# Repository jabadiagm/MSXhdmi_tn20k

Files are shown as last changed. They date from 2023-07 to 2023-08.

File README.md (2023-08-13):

# MSXhdmi_tn20k
Adaptador hdmi para MSX1 / MSX1 hdmi adapter

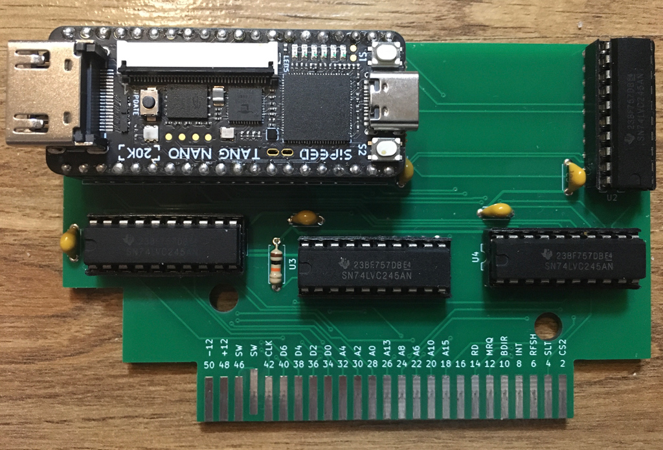
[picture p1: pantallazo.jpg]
Pantallazo


Permite conectar un MSX de primera generación a un monitor convencional. La lógica está contenida en una Tang Nano 20K que se encarga de reproducir imagen (vdp) y sonido (psg + fm + scc). Parcialmente compatible con el software MSX2. Adaptación del vdp V9958 escrita por [lfantoniosi](https://github.com/lfantoniosi).

Configuración de sofarun para utilizar scc externa:

[https://www.msx.org/forum/msx-talk/hardware/report-konami-scc-standalone-with-sofarun](https://www.msx.org/forum/msx-talk/hardware/report-konami-scc-standalone-with-sofarun)

Allows the conection between a first generation MSX and a conventional monitor. Logic is contained in a Tang Nano 20K which is in charge of playing picture (vdp) and sound (psg + fm + scc). Partially compatible with MSX2 software. V9958 adapted by [lfantoniosi](https://github.com/lfantoniosi).

sofarun config using external scc:

[https://www.msx.org/forum/msx-talk/hardware/report-konami-scc-standalone-with-sofarun](https://www.msx.org/forum/msx-talk/hardware/report-konami-scc-standalone-with-sofarun)

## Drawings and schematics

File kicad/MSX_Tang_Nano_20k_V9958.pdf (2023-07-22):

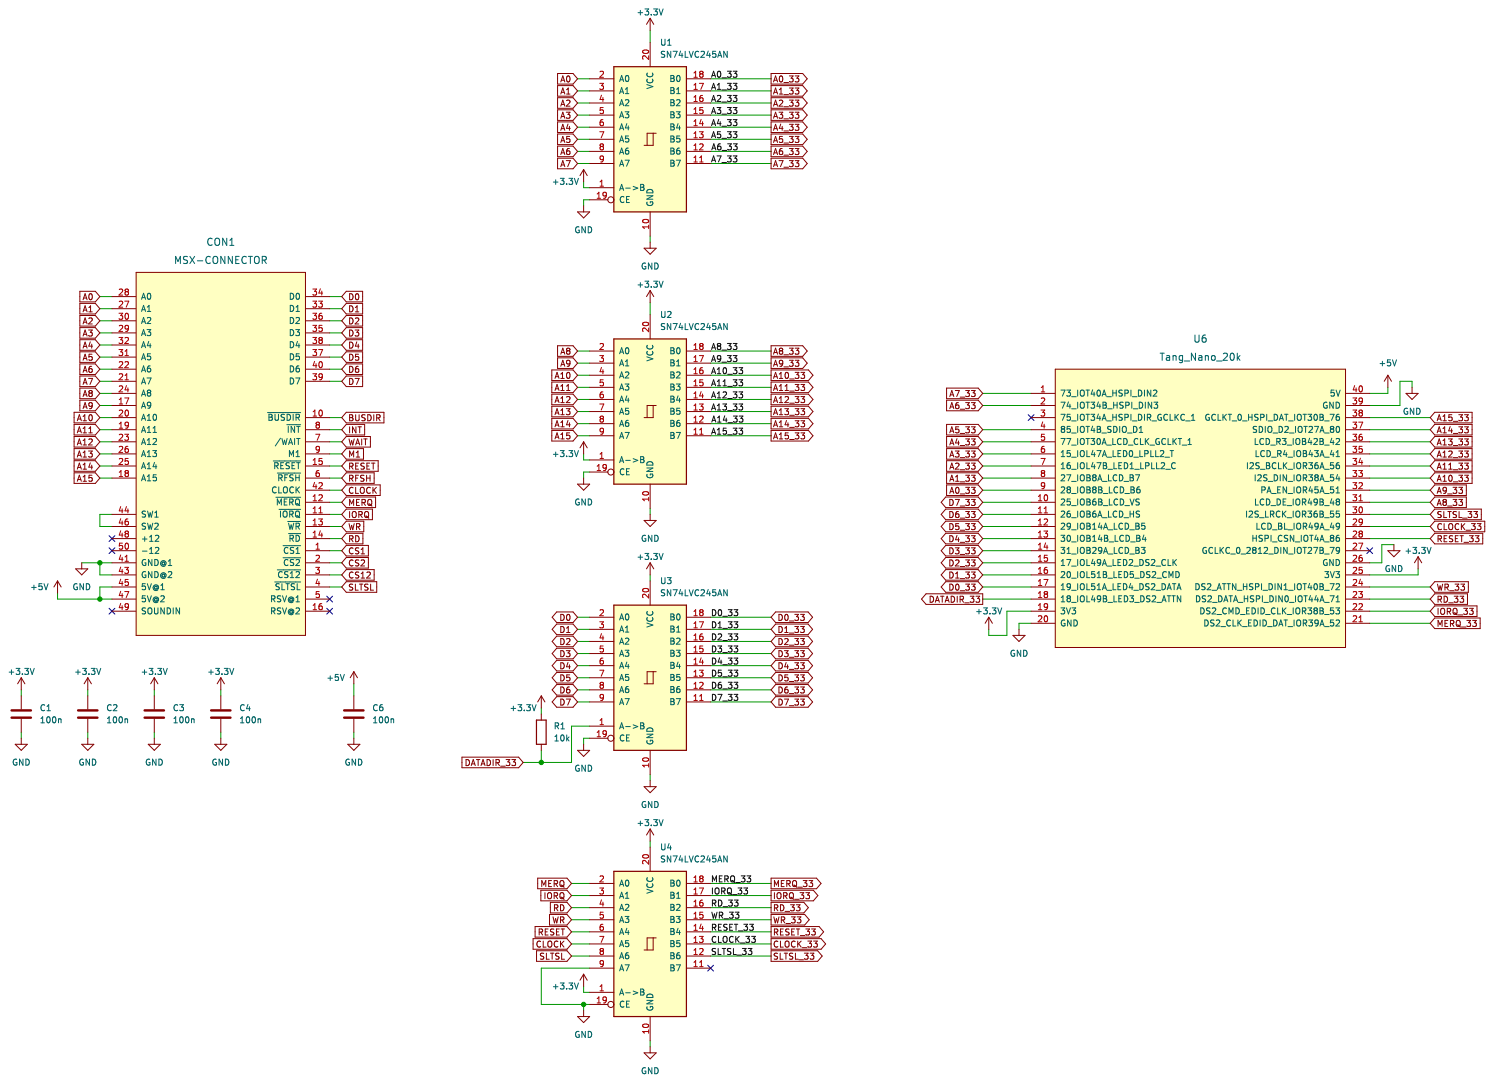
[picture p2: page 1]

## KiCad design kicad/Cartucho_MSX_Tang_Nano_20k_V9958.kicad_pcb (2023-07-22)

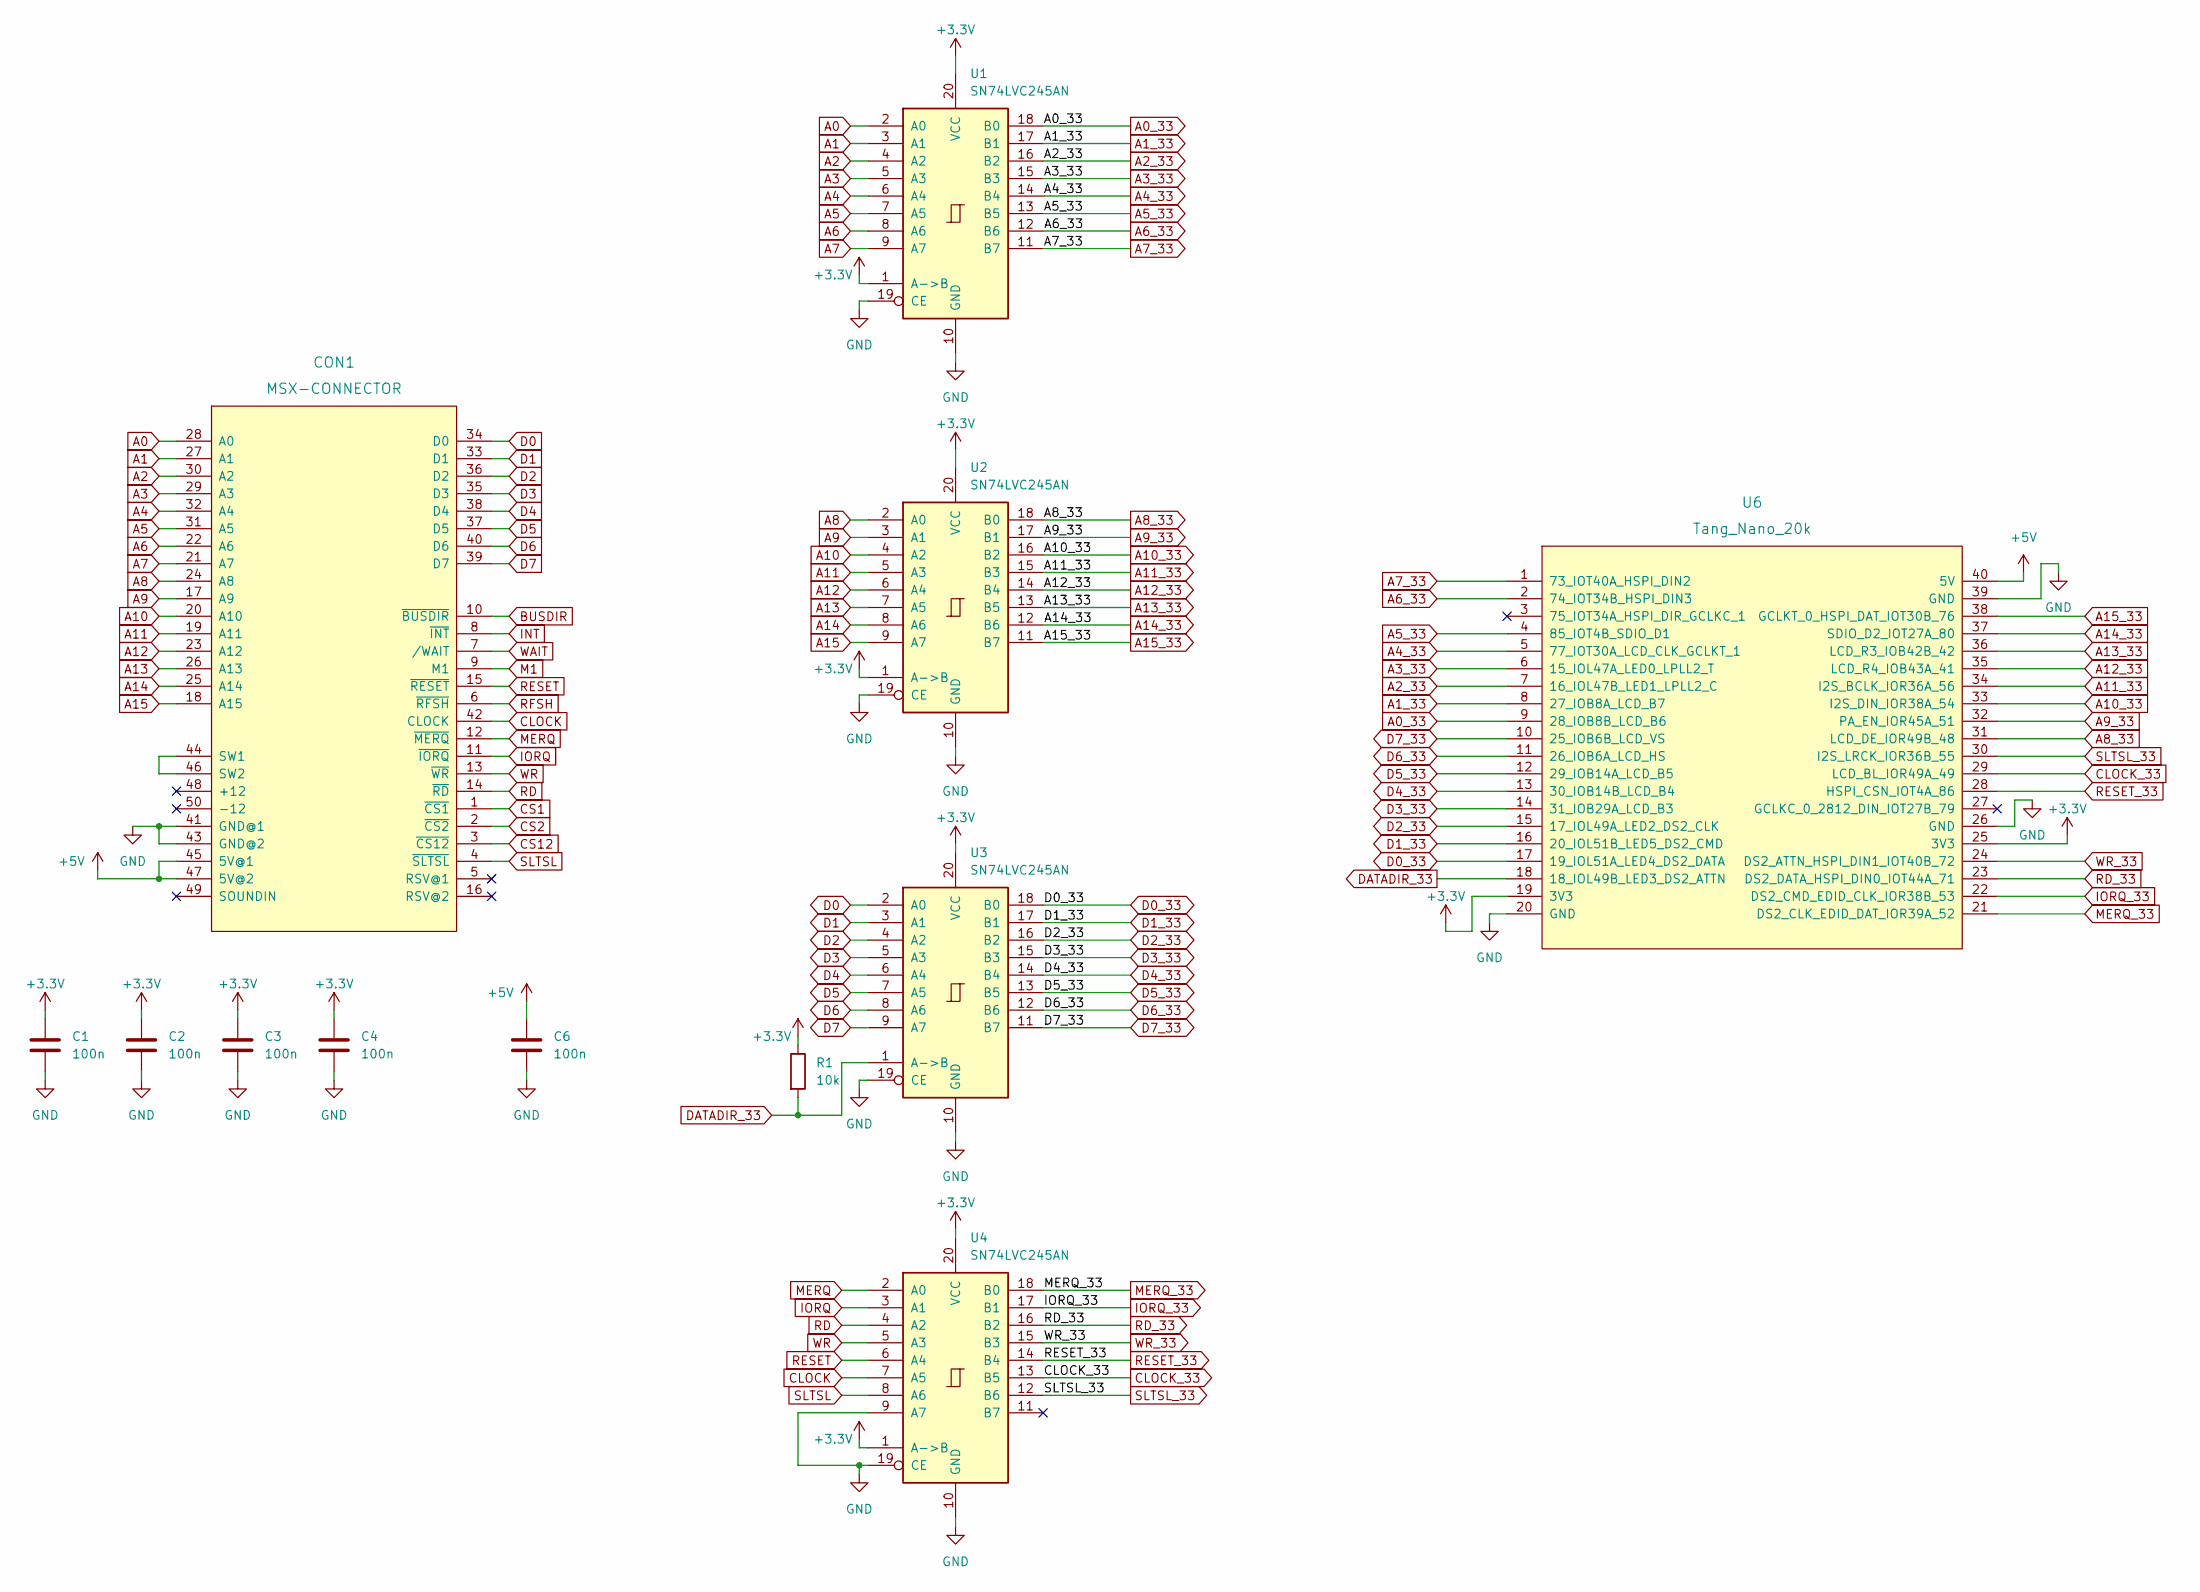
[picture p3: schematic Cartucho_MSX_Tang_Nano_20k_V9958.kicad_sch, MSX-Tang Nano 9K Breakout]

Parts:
C1, C2, C3, C4, C6: 100n; C_Disc_D4.3mm_W1.9mm_P5.00mm
CON1: MSX-CONNECTOR; CARTRIDGE_MSX
R1: 10k; R_Axial_DIN0207_L6.3mm_D2.5mm_P7.62mm_Horizontal
U1, U2, U3, U4: SN74LVC245AN; DIP-20_W7.62mm_LongPads
U6: Tang_Nano_20k

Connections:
+3.3V: C1.1, C2.1, C3.1, C4.1, R1.1, U1.1 (A->B), U1.20 (VCC), U2.1 (A->B), U2.20 (VCC), U3.20 (VCC), U4.1 (A->B), U4.20 (VCC), U6.19 (3V3), U6.25 (3V3)
+5V: C6.1, CON1.45 (5V@1), CON1.47 (5V@2), U6.40 (5V)
A0: CON1.28 (A0), U1.2 (A0)
A0_33: U1.18 (B0), U6.9 (28_IOB8B_LCD_B6)
A1: CON1.27 (A1), U1.3 (A1)
A1_33: U1.17 (B1), U6.8 (27_IOB8A_LCD_B7)
A2: CON1.30 (A2), U1.4 (A2)
A2_33: U1.16 (B2), U6.7 (16_IOL47B_LED1_LPLL2_C)
A3: CON1.29 (A3), U1.5 (A3)
A3_33: U1.15 (B3), U6.6 (15_IOL47A_LED0_LPLL2_T)
A4: CON1.32 (A4), U1.6 (A4)
A4_33: U1.14 (B4), U6.5 (77_IOT30A_LCD_CLK_GCLKT_1)
A5: CON1.31 (A5), U1.7 (A5)
A5_33: U1.13 (B5), U6.4 (85_IOT4B_SDIO_D1)
A6: CON1.22 (A6), U1.8 (A6)
A6_33: U1.12 (B6), U6.2 (74_IOT34B_HSPI_DIN3)
A7: CON1.21 (A7), U1.9 (A7)
A7_33: U1.11 (B7), U6.1 (73_IOT40A_HSPI_DIN2)
A8: CON1.24 (A8), U2.2 (A0)
A8_33: U2.18 (B0), U6.31 (LCD_DE_IOR49B_48)
A9: CON1.17 (A9), U2.3 (A1)
A9_33: U2.17 (B1), U6.32 (PA_EN_IOR45A_51)
A10: CON1.20 (A10), U2.4 (A2)
A10_33: U2.16 (B2), U6.33 (I2S_DIN_IOR38A_54)
A11: CON1.19 (A11), U2.5 (A3)
A11_33: U2.15 (B3), U6.34 (I2S_BCLK_IOR36A_56)
A12: CON1.23 (A12), U2.6 (A4)
A12_33: U2.14 (B4), U6.35 (LCD_R4_IOB43A_41)
A13: CON1.26 (A13), U2.7 (A5)
A13_33: U2.13 (B5), U6.36 (LCD_R3_IOB42B_42)
A14: CON1.25 (A14), U2.8 (A6)
A14_33: U2.12 (B6), U6.37 (SDIO_D2_IOT27A_80)
A15: CON1.18 (A15), U2.9 (A7)
A15_33: U2.11 (B7), U6.38 (GCLKT_0_HSPI_DAT_IOT30B_76)
BUSDIR: CON1.10 (~BUSDIR)
CLOCK: CON1.42 (CLOCK), U4.7 (A5)
CLOCK_33: U4.13 (B5), U6.29 (LCD_BL_IOR49A_49)
CS1: CON1.1 (~CS1)
CS2: CON1.2 (~CS2)
CS12: CON1.3 (~CS12)
D0: CON1.34 (D0), U3.2 (A0)
D0_33: U3.18 (B0), U6.17 (19_IOL51A_LED4_DS2_DATA)
D1: CON1.33 (D1), U3.3 (A1)
D1_33: U3.17 (B1), U6.16 (20_IOL51B_LED5_DS2_CMD)
D2: CON1.36 (D2), U3.4 (A2)
D2_33: U3.16 (B2), U6.15 (17_IOL49A_LED2_DS2_CLK)
D3: CON1.35 (D3), U3.5 (A3)
D3_33: U3.15 (B3), U6.14 (31_IOB29A_LCD_B3)
D4: CON1.38 (D4), U3.6 (A4)
D4_33: U3.14 (B4), U6.13 (30_IOB14B_LCD_B4)
D5: CON1.37 (D5), U3.7 (A5)
D5_33: U3.13 (B5), U6.12 (29_IOB14A_LCD_B5)
D6: CON1.40 (D6), U3.8 (A6)
D6_33: U3.12 (B6), U6.11 (26_IOB6A_LCD_HS)
D7: CON1.39 (D7), U3.9 (A7)
D7_33: U3.11 (B7), U6.10 (25_IOB6B_LCD_VS)
DATADIR_33: R1.2, U3.1 (A->B), U6.18 (18_IOL49B_LED3_DS2_ATTN)
GND: C1.2, C2.2, C3.2, C4.2, C6.2, CON1.41 (GND@1), CON1.43 (GND@2), U1.10 (GND), U1.19 (CE), U2.10 (GND), U2.19 (CE), U3.10 (GND), U3.19 (CE), U4.9 (A7), U4.10 (GND), U4.19 (CE), U6.20 (GND), U6.26 (GND), U6.39 (GND)
INT: CON1.8 (~INT)
IORQ: CON1.11 (~IORQ), U4.3 (A1)
IORQ_33: U4.17 (B1), U6.22 (DS2_CMD_EDID_CLK_IOR38B_53)
M1: CON1.9 (M1)
MERQ: CON1.12 (~MERQ), U4.2 (A0)
MERQ_33: U4.18 (B0), U6.21 (DS2_CLK_EDID_DAT_IOR39A_52)
unnamed: CON1.44 (SW1), CON1.46 (SW2)
RD: CON1.14 (~RD), U4.4 (A2)
RD_33: U4.16 (B2), U6.23 (DS2_DATA_HSPI_DIN0_IOT44A_71)
RESET: CON1.15 (~RESET), U4.6 (A4)
RESET_33: U4.14 (B4), U6.28 (HSPI_CSN_IOT4A_86)
RFSH: CON1.6 (~RFSH)
SLTSL: CON1.4 (~SLTSL), U4.8 (A6)
SLTSL_33: U4.12 (B6), U6.30 (I2S_LRCK_IOR36B_55)
WAIT: CON1.7 (/WAIT)
WR: CON1.13 (~WR), U4.5 (A3)
WR_33: U4.15 (B3), U6.24 (DS2_ATTN_HSPI_DIN1_IOT40B_72)

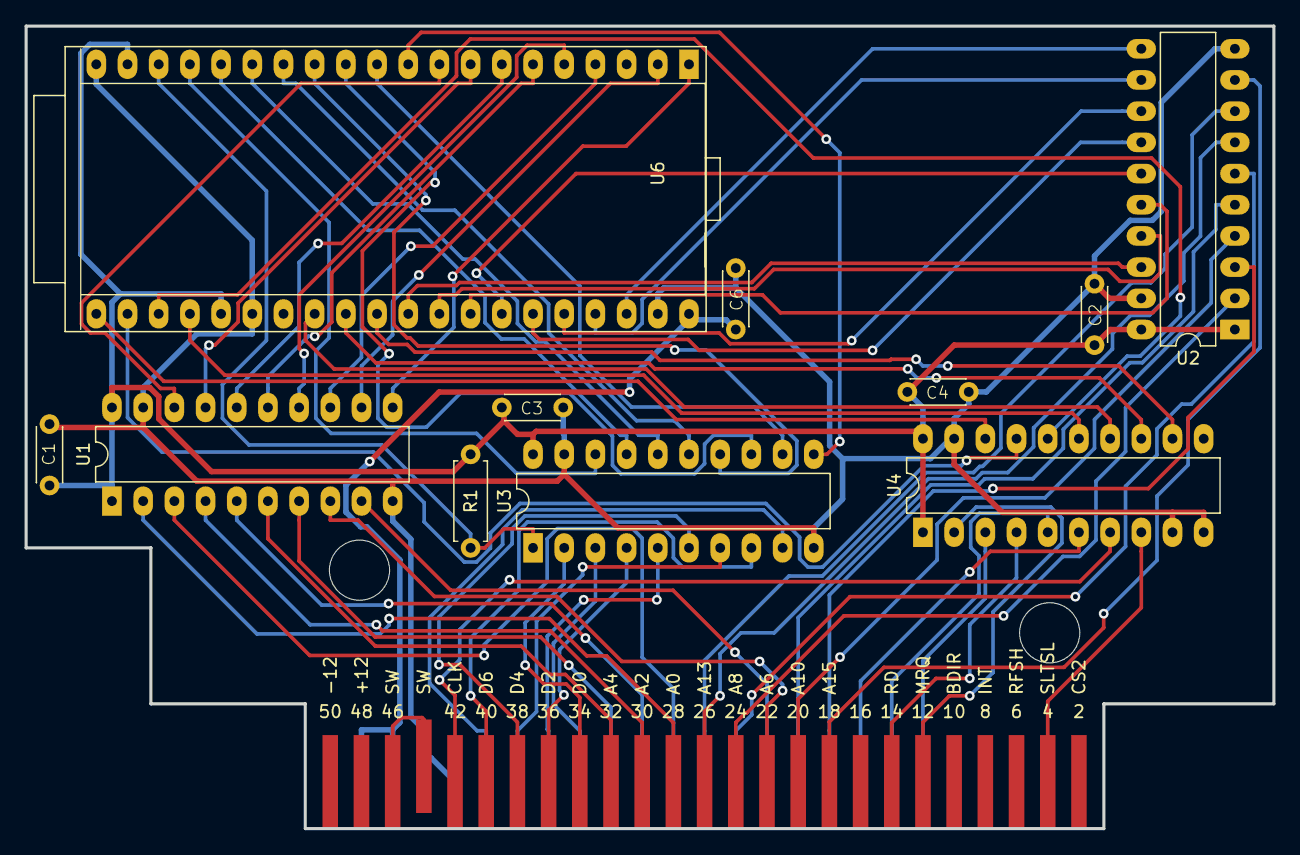
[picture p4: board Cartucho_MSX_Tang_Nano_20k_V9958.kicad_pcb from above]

Board: 2 copper layers, 101.6 x 65.3 mm, 12 parts (0 on the bottom side), 67 nets.

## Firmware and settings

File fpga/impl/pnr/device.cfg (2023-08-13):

set JTAG regular_io = false
set SSPI regular_io = true
set MSPI regular_io = false
set READY regular_io = false
set DONE regular_io = false
set RECONFIG_N regular_io = false
set I2C regular_io = false
set CRC_check = true
set compress = false
set encryption = false
set security_bit_enable = true
set bsram_init_fuse_print = true
set background_programming = off
set secure_mode = false
set download_speed = 250/10
set program_done_bypass = false
set wake_up = 0
set spi_flash_address = 0x00000000
set format = binary
set power_on_reset_monitor = true
set unused_pin = default

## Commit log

2023-07-22 Cambiada distribución de pines Incluída rom FM Incluída pcb kicad
    -------------------------
    Updated pinout
    Included fm rom
    Included kicad pcb
    [Cartucho_MSX_Tang_Nano_20k_V9958-B_Mask.gbs, Cartucho_MSX_Tang_Nano_20k_V9958-B_Paste.gbp, Cartucho_MSX_Tang_Nano_20k_V9958-B_Silkscreen.gbo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]
2023-07-26 Corregido bug de dirección de bus
    ---------------------------------
    Fixed bug with busdir
2023-08-13 Añadido soporte básico para sonido scc
    ------------------------------------
    Included basic support for scc sound
    [device.cfg]
